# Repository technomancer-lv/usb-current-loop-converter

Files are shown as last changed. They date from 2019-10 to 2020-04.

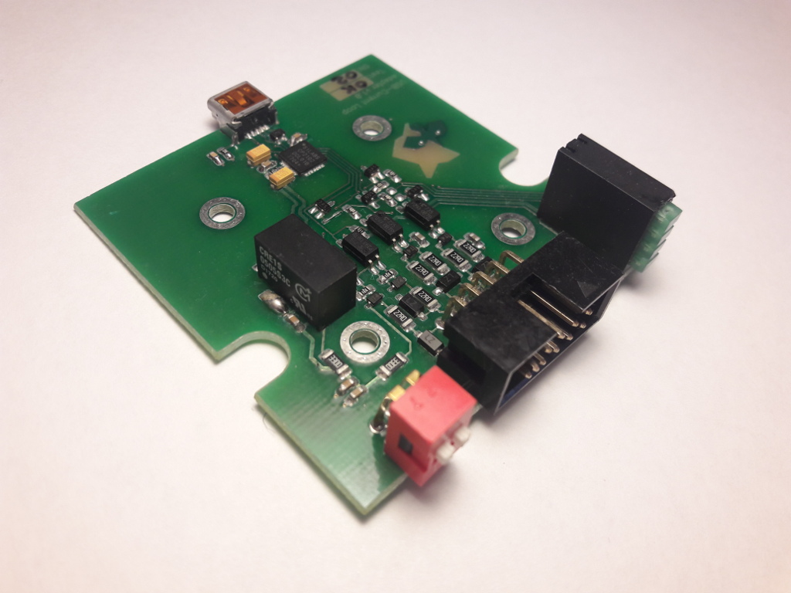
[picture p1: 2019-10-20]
pictures/01-cl-interface-top-1.jpg

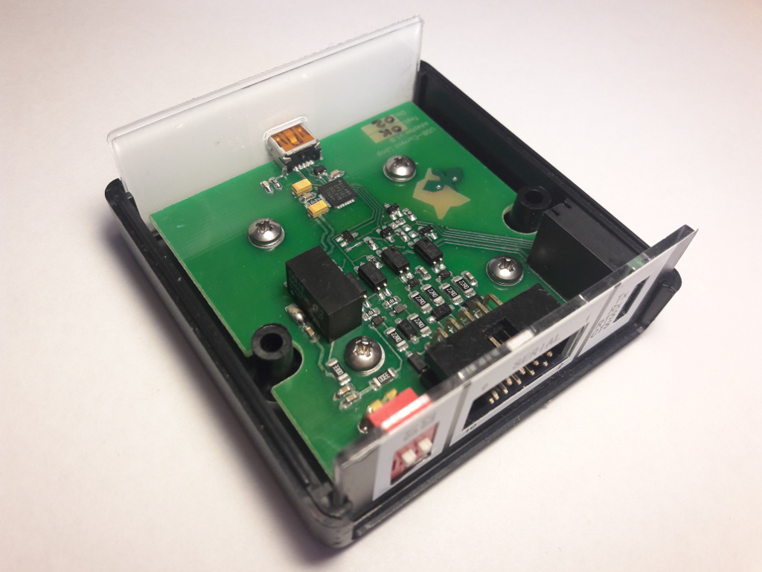
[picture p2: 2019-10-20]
pictures/04-cl-interface-in-case.jpg

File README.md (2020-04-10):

### What's this project for?
Current loop communication interface is used in various old computing equipment - computers, terminals, printers and other devices. This converter is made to let these devices interface with modern computers over USB port. It's based on CP2102 USB-serial bridge and can work up to 19200 baud.It's tested as working with soviet made PDP-11 compatible boards MS1201.01, 02, 03 (МС1201), computer DVK-3 (ДВК-3) or DVK-3M (ДВК-3М), serial interfaces UPO (УПО), I12 (И12), KTLK(КТЛК), KTLK-6 and also with terminals MS6102.02 (МС6102.02) and 15IE-00-013 (15ИЭ-00-013).

Converter is made as completed device in case that need only USB and current loop serial connections. Status of Tx, Rx, RTS and CTS lines are displayed on LEDs. Also, RTS and CTS signals can be forced to be active using DIP switches.

### What's the status of this project?
v1.0 is made and tweaked to work with various soviet made computing equipment. I have several of these converters in use and two are sold with good feedbacks from the buyers. Hardware version 1.2 is almost ready to be ordered. There are pulse stretcher for LEDs, so data activity will be displayed more visible. Data rate in prototype is 19200 bps.

Finished set will include:
  - Adapter itself
  - 0,5m long USB-mini cable
  - 1m long 10pin cable for connecting adapeter to 10pin interfaces
  - Small board for connecting 8pin interface to 10pin cable
  - Loopback connector
  
Additional parts possible:
  - Current loop interface cable for any other equipment, that's not supported by original adapter
  - Adapter board for connecting I12 serial controller to RS-232

### How to use it?
First, connect adapter to your computer with USB-mini cable. New serial port should appear in your system. If there's no new device found in your system, this might be a driver problem. You can download CP2102 drivers here:\
https://www.silabs.com/products/development-tools/software/usb-to-uart-bridge-vcp-drivers \
If you open terminal emulator (i.e. Realterm in Win or minicom in Linux) on this new port and type something, you should see Tx LED blinking as you type. You can test receive functionality of adapter with loopback plug. Connect it to serial port of your adapter and type something in terminal emulator. You should see both Tx and Rx LEDs blinking and symbols you type should echo back in terminal emulator screen.\
To connect emulator to your PDP-11 machine, use cable that comes with emulator. Cable can be directly connected to MS1201.02, .03 and .04 board terminal port and also DVK-3M terminal port. If boards with 8-pin connector needs to be connected (for example, UPO, I12, MS1201.01 or older revisions of .02), it can be done with adapter board. Simply connect cable to adapter board and plug it into terminal port of your retro computer. RTS and/or CTS might have to be forced on, otherwse computer might refuse to send data.\
Be sure that baudrate of terminal emulator is set correctly, switch on your PDP-11 compatible machine and you should see ODT prompt. That's it!

### What has to be done?
v1.2 should be properly tested on various equipment\
v1.2 should be properly packed up and sold in soviet retro computer related forums

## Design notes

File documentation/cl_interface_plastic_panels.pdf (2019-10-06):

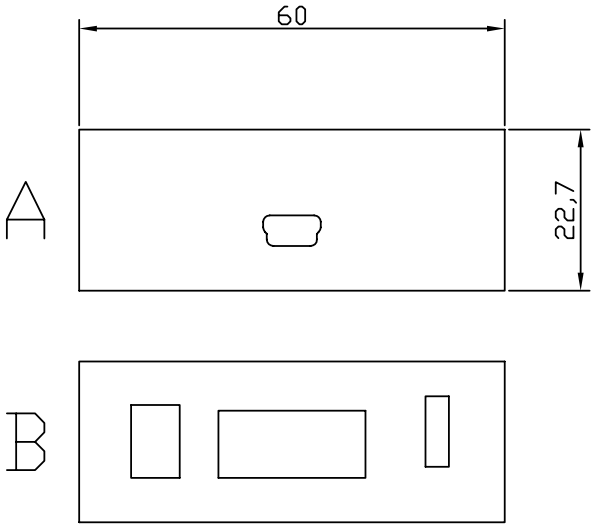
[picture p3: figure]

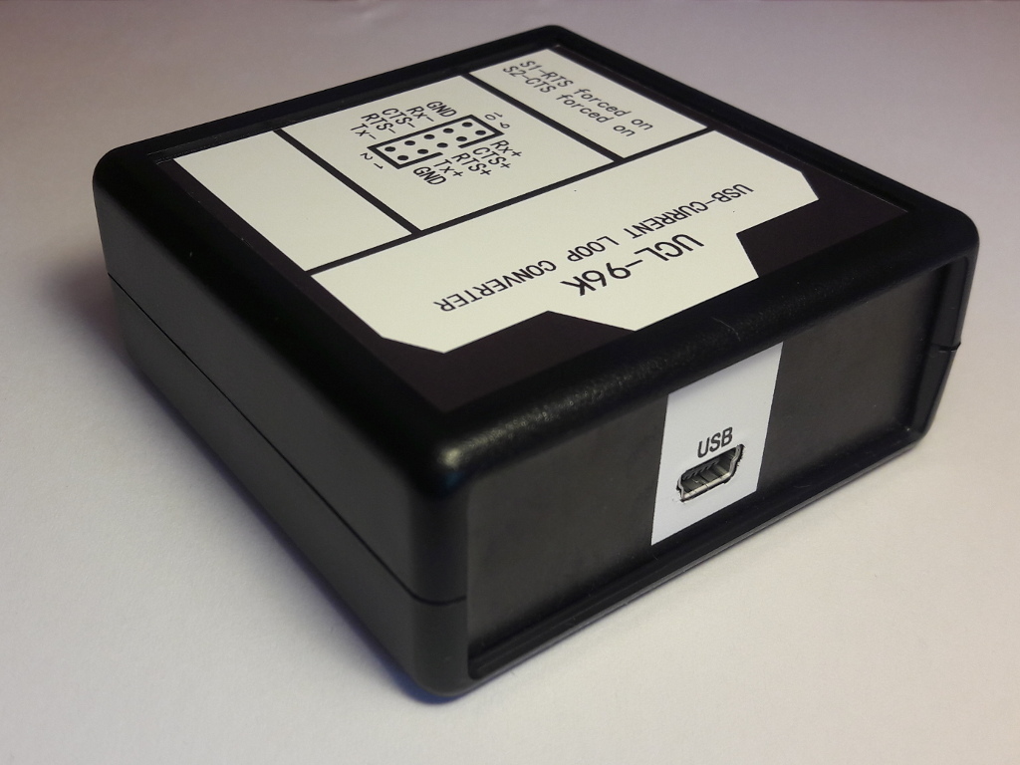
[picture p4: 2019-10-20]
pictures/06-cl-interface.jpg

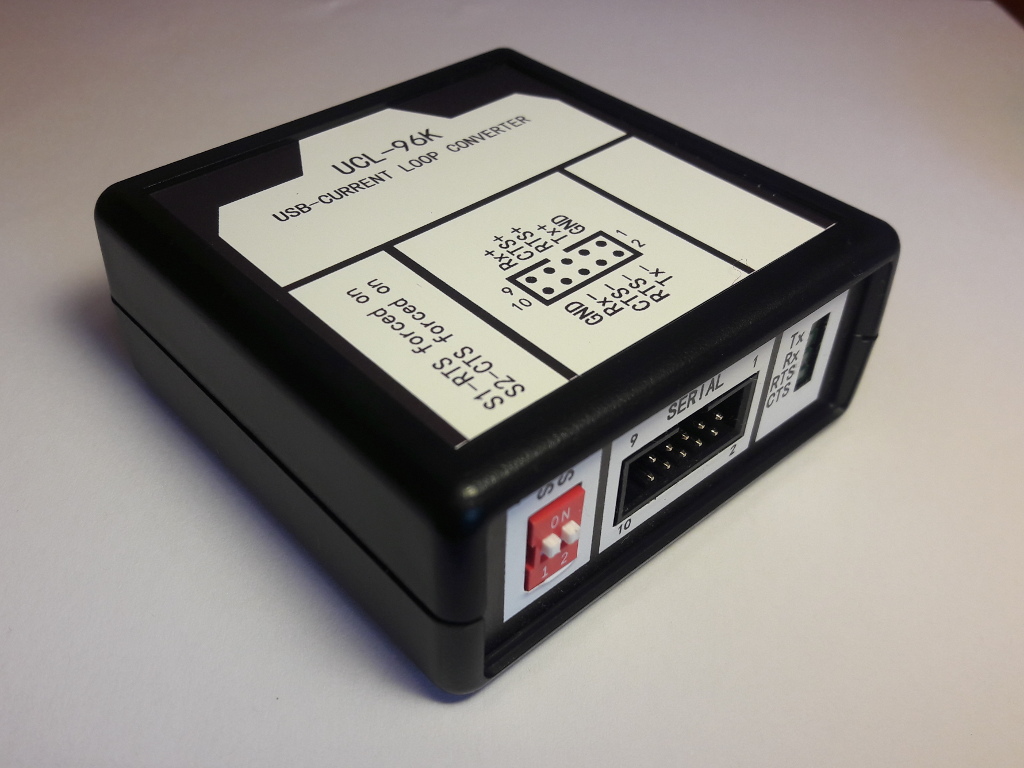
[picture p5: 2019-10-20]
pictures/05-cl-interface.jpg

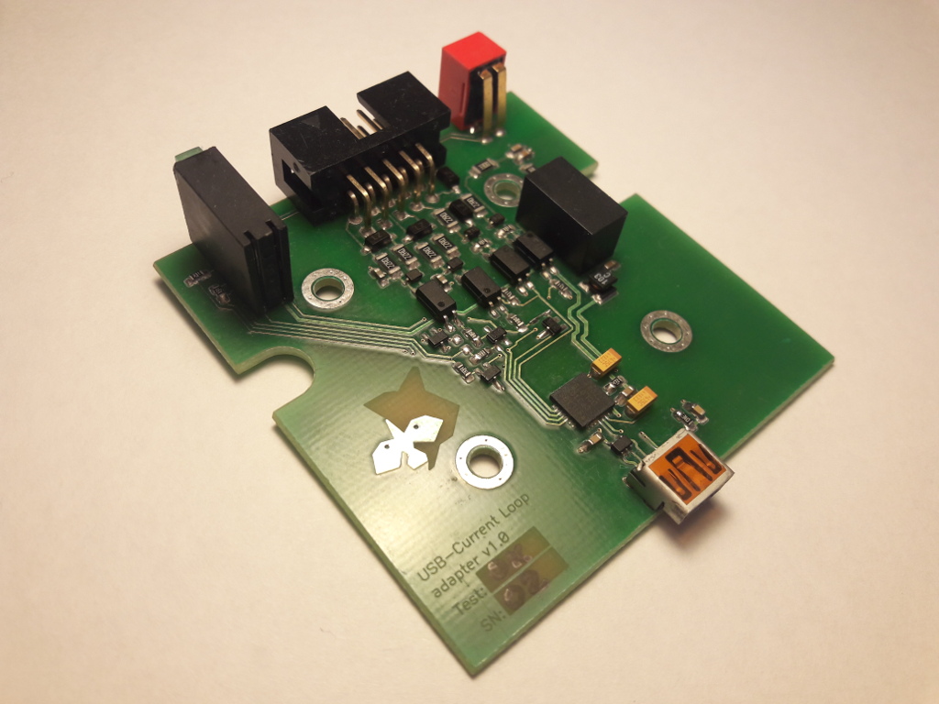
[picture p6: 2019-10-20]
pictures/02-cl-interface-top-2.jpg

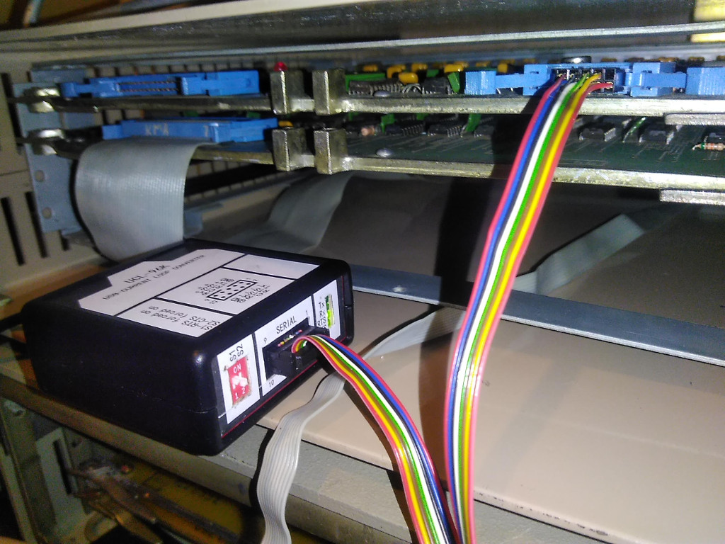
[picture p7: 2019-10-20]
pictures/07-cl-interface-connected.jpg

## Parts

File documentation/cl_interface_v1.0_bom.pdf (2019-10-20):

Sheet1

Page 1

RefDes | Part number | Count | Distributor | Order Nr. | Remarks | Price, each, Eur | Price per board
C1 | | 1 Ormix | | | 4700pF, 0603 | 0,03 | 0,03
C2,C4,C6,C9 | | 4 Ormix | | | 0,1uF 0603 | 0,03 | 0,12
C3,C5 | TAJA475K016R | 2 Ormix | | | 4,7uF, type A tantalum | 0,25 | 0,5
C7, C8 | | 2 Ormix | | | 1,0uF, 0603 | 0,05 | 0,1
C10,C11 | | 2 Ormix | | | 1500pF | 0,03 | 0,06
D1 | SP0504BAJTG | 1 Farnell | | | 1,05 | 1,05
D2, D3, D4, D5, D6 | 1N4148WS | 5 Ormix | | | 0,2 | 1
D7, D8, D9, D10 | ATV02W240B-HF | 4 Digikey | 641-1660-1-ND | EOL? | 0,37 | 1,48
JP1 | 51387-0578 | 1 Farnell | 2751685 | 1,01 | 1,01
JP2 | BH1R-10 | 1 Ormix | | 0,23 | 0,23
L1 | 82103C | 1 Digikey | 811-2473-1-ND | 0,32 | 0,32
LED1 | WP914CK/4GDT | 1 Digikey | 754-1286-ND | 1,5 | 1,5
Q1, Q2, Q3 | BC807-25WT1G | 3 Farnell | 2533298 | 0,13 | 0,39
Q4 | | 1 Farnell | 8737045 | 0,17 | 0,17
R1 | 0603-1M-F 0603-4.7K-F | 1 Ormix | | 0,005 | 0,005
R2 | | 1 Ormix | | 0,004 | 0,004
R3, R4 | | 2 Ormix | Optional | | 0
R5, R7, R8, R9 | 0603-330om-F | 4 Ormix | | 0,004 | 0,016
R6 | | 1 Ormix | Unpopulated | | 0
R10, R11 | 0603-470om-F 0603-68om-F 0603-330om-F 1206-330om-F 1206-22om-F | 2 Ormix | | 0,004 | 0,008
R12, R13 | | 2 Ormix | | 0,004 | 0,008
R14, R15 | | 2 Ormix | | 0,004 | 0,008
R16, R17 | | 2 Ormix | | 0,02 | 0,04
R18, R19, R20, R21, R22, R23 | | 6 Ormix | | 0,02 | 0,12
SW1 | MCDA02 | 1 Farnell | 1255229 | EOL | 0
U1 | CP2102-GM | 1 Farnell | 9282130 | | 3,16 | 3,16
U2 | CRE1S0505S3C | 1 Farnell | 2564448 | Optional | 2,46 | 2,46
U3, U4, U5, U6 | TLP293 | 4 Farnell | 2524317 | | 0,386 | 1,544
PCB | According to gerber files | 1 JLCPCB | | | 3 | 3
Case | 1593KBK | 1 Farnell | 930180 | Plastic panels replaced with custom ones | 2,98 | 2,98
Screws | | 4 Delve2 | | For fixing PCB in case | 0,05 | 0,2
Plastic panels | According to drawings | 1 Kviller | | | 1,5 | 1,5
Stickers | According to drawings | 1 CopyPro | | | | 0
Ormix – local radio parts shop | Price, overall (No VAT): | 23,013
Delve2 – local screw shop | Price (+VAT): | 27,84573
Kviller – local laser cutting contractor
CopyPro – local printing service

Additional parts:
Interconnect cable
IDC connector | FC-10 | 1 Ormix | 0
Cable | F0801-10P | 1 Ormix | 0
| | | 0
| | | 0
Serial cable:
Mini USB cable

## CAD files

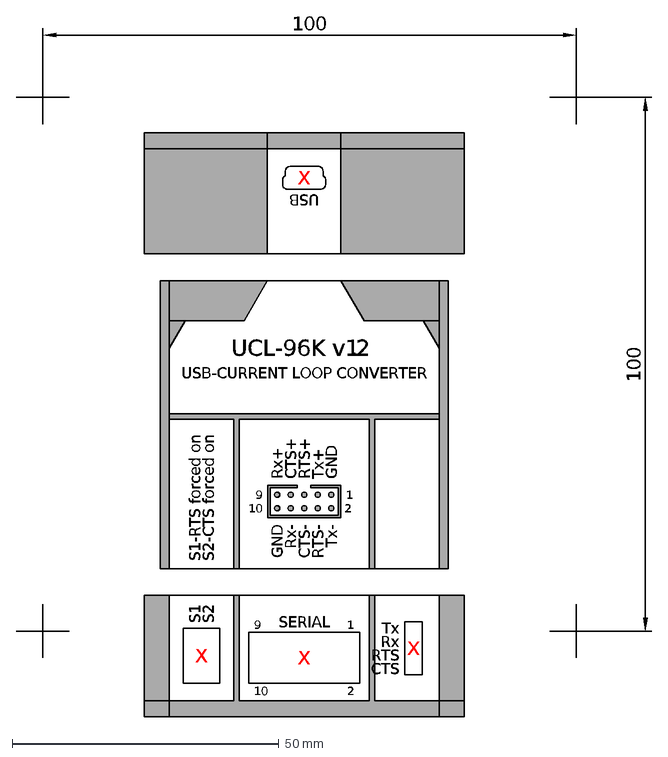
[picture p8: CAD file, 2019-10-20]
cad/stickers.dxf
Tx
Rx
RTS
CTS
S1
S2
SERIAL
USB
1
2
9
10
S1-RTS forced on
S2-CTS forced on
Tx-
CTS-
RTS-
Rx-
GND
Tx+
CTS+
RTS+
Rx+
X
UCL-96K v1
USB-CURRENT LOOP CONVERTER
100
.

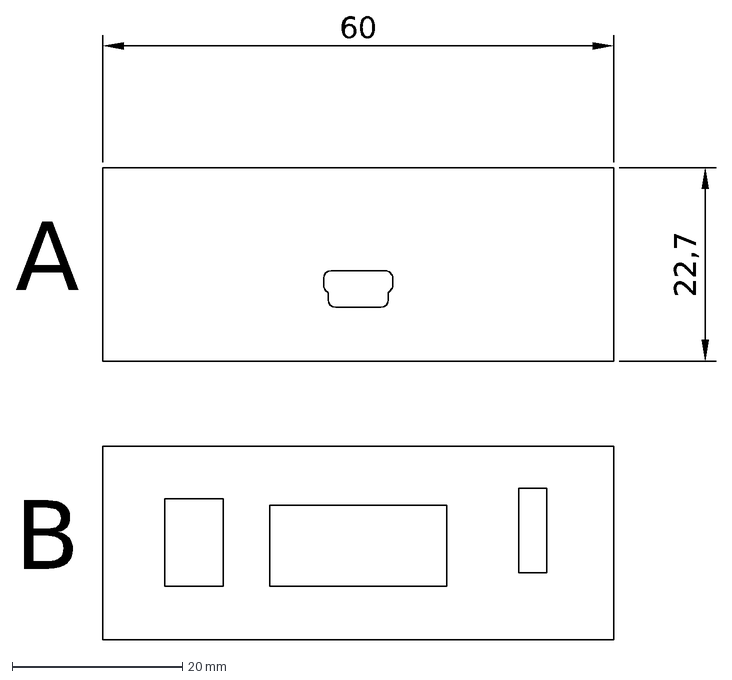
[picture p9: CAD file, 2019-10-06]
cad/plastic_panels.dxf
60
22,7
A
B

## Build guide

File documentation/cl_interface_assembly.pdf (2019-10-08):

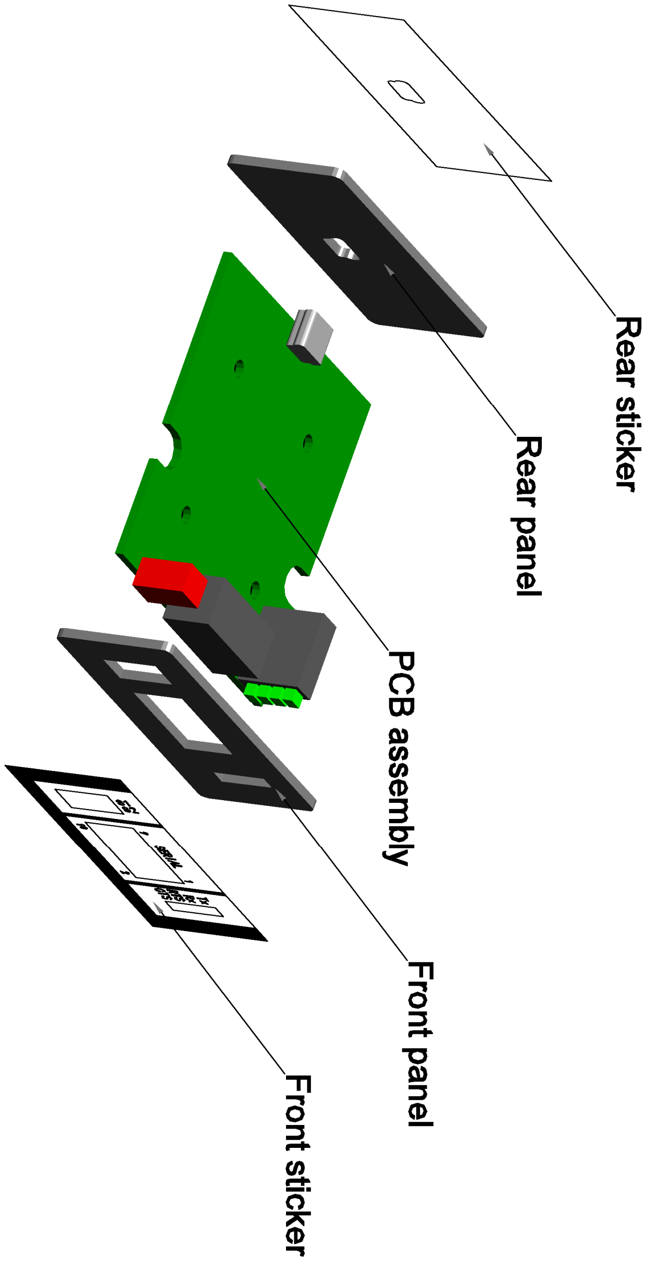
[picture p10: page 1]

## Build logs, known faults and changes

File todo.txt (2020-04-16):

Workflow 2020:
	Make cables (17.02) (6pcs made, waiting for connectors)
	Solder adapter boards (5 done, waiting for connectors)
	Test all sets
	Put all in boxes (converter, small board, loopback plug, interface cable, USB cable, sticker)
	Sell 8pcs
	
	Add finished set pictures here

v1.2:	sch:
	BOM should be re-checked when finished - count, values, links
      
  another small PCB for 8-pin connector
	check if everything fits and works on 1201, UPO and I12 boards (1201 and UPO tested)
	also make 8pin-DE9M adapter for I12 (witn insulators?) (unrelated to CL, only RS232)
    
  make full documentation
  make BOM
  proper testing (MS1201.01 .02 .03, terminals)
  cable pinouts for various devices and loopback cable
  better assembly drawing
    
  make set for sale
    make pictures with packed up set
    make pictures with new version and adapter boards
    
Maybe cheap lite version with no case, no RST/CTS, all DIP?
    With cheap ebay UART module
    Component values on board
    Sold as simple board to be assembled by buyer

Design a convertor for RS232-IRPS
Maybe one with BK KMK module compatible pinout?
Maybe one with MC6102 optical UART compatibility?

Issues:
  A bit incorrect resistor numbering at the CL connector. Fix in next release if there will be one.

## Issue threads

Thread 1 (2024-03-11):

FEATURE REQUEST: Export .pcb files as PCAD ASCII PCB files

nightgryphon, 2024-03-11:
Пожалуйста, могли бы вы экспортировать файлы печатных плат в ASCII PCB формате? BIN PCB формат не берет KiCAD к сожалению. Хотел собрать панель для самостоятельной распилки с переходниками вместе...

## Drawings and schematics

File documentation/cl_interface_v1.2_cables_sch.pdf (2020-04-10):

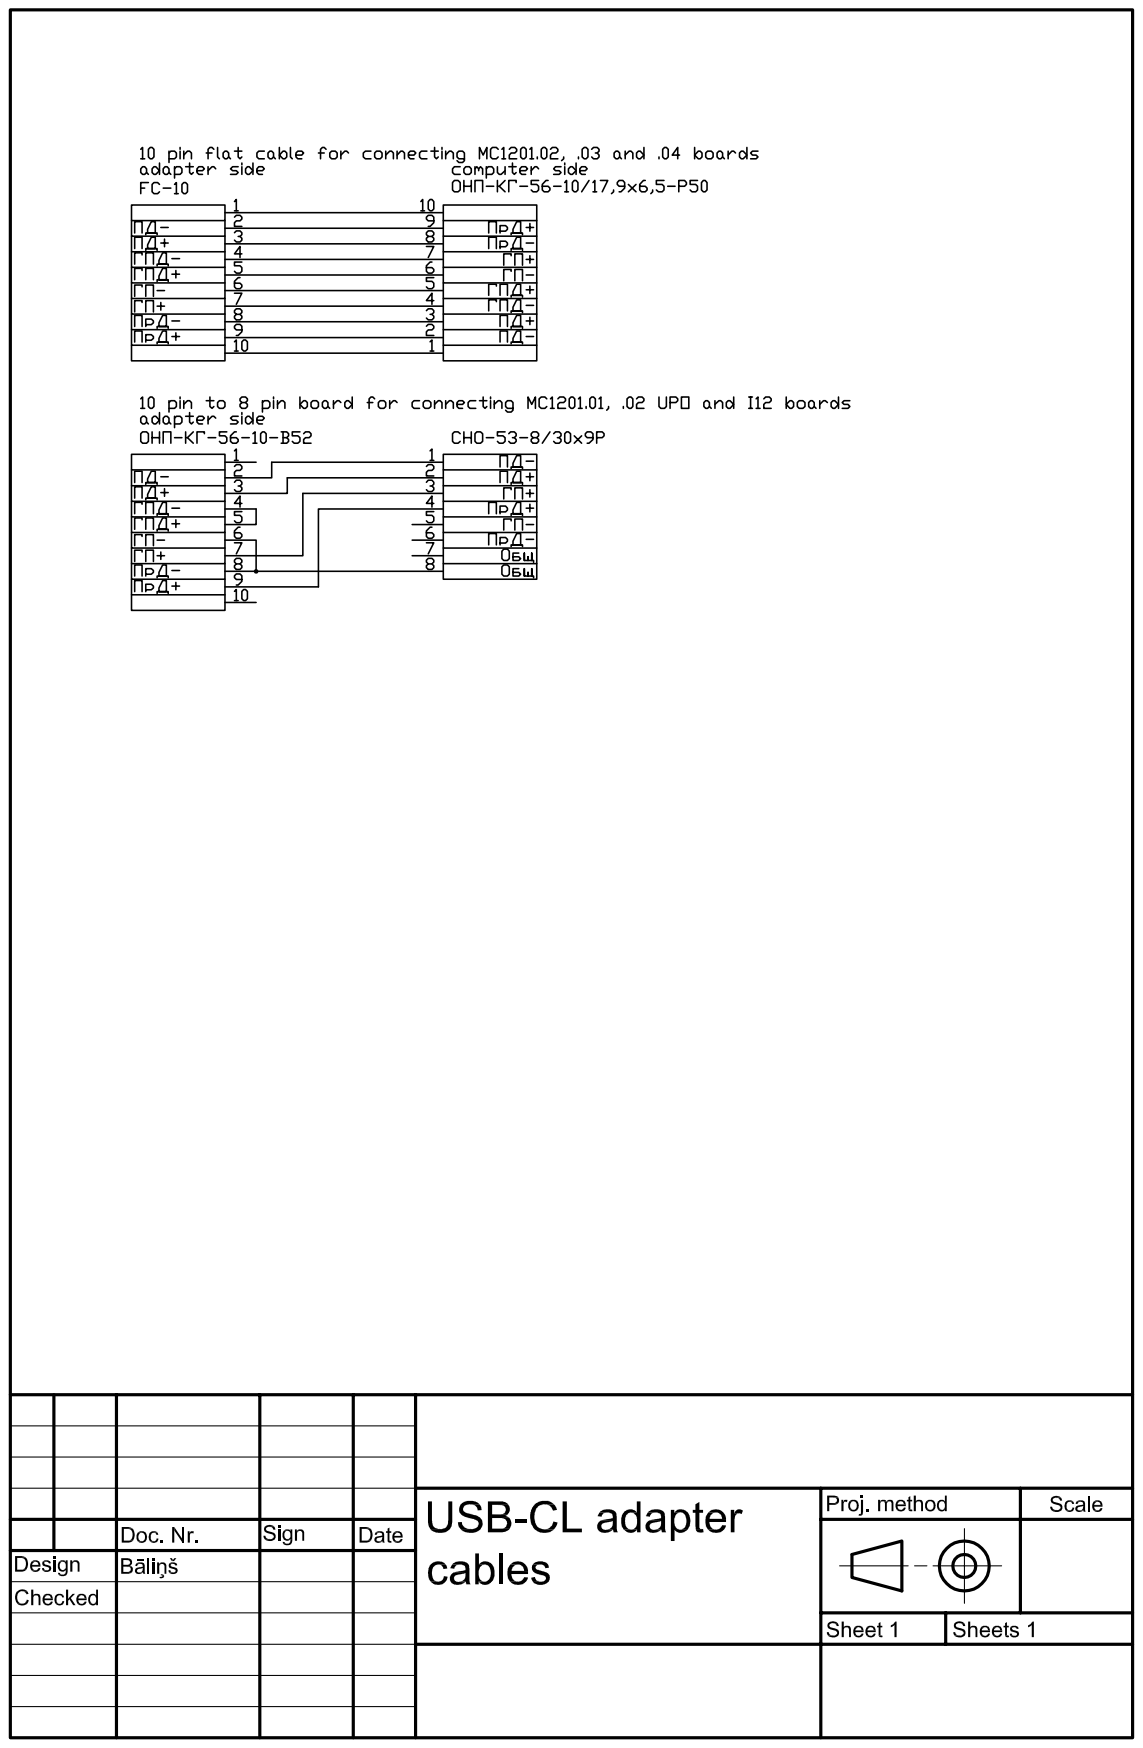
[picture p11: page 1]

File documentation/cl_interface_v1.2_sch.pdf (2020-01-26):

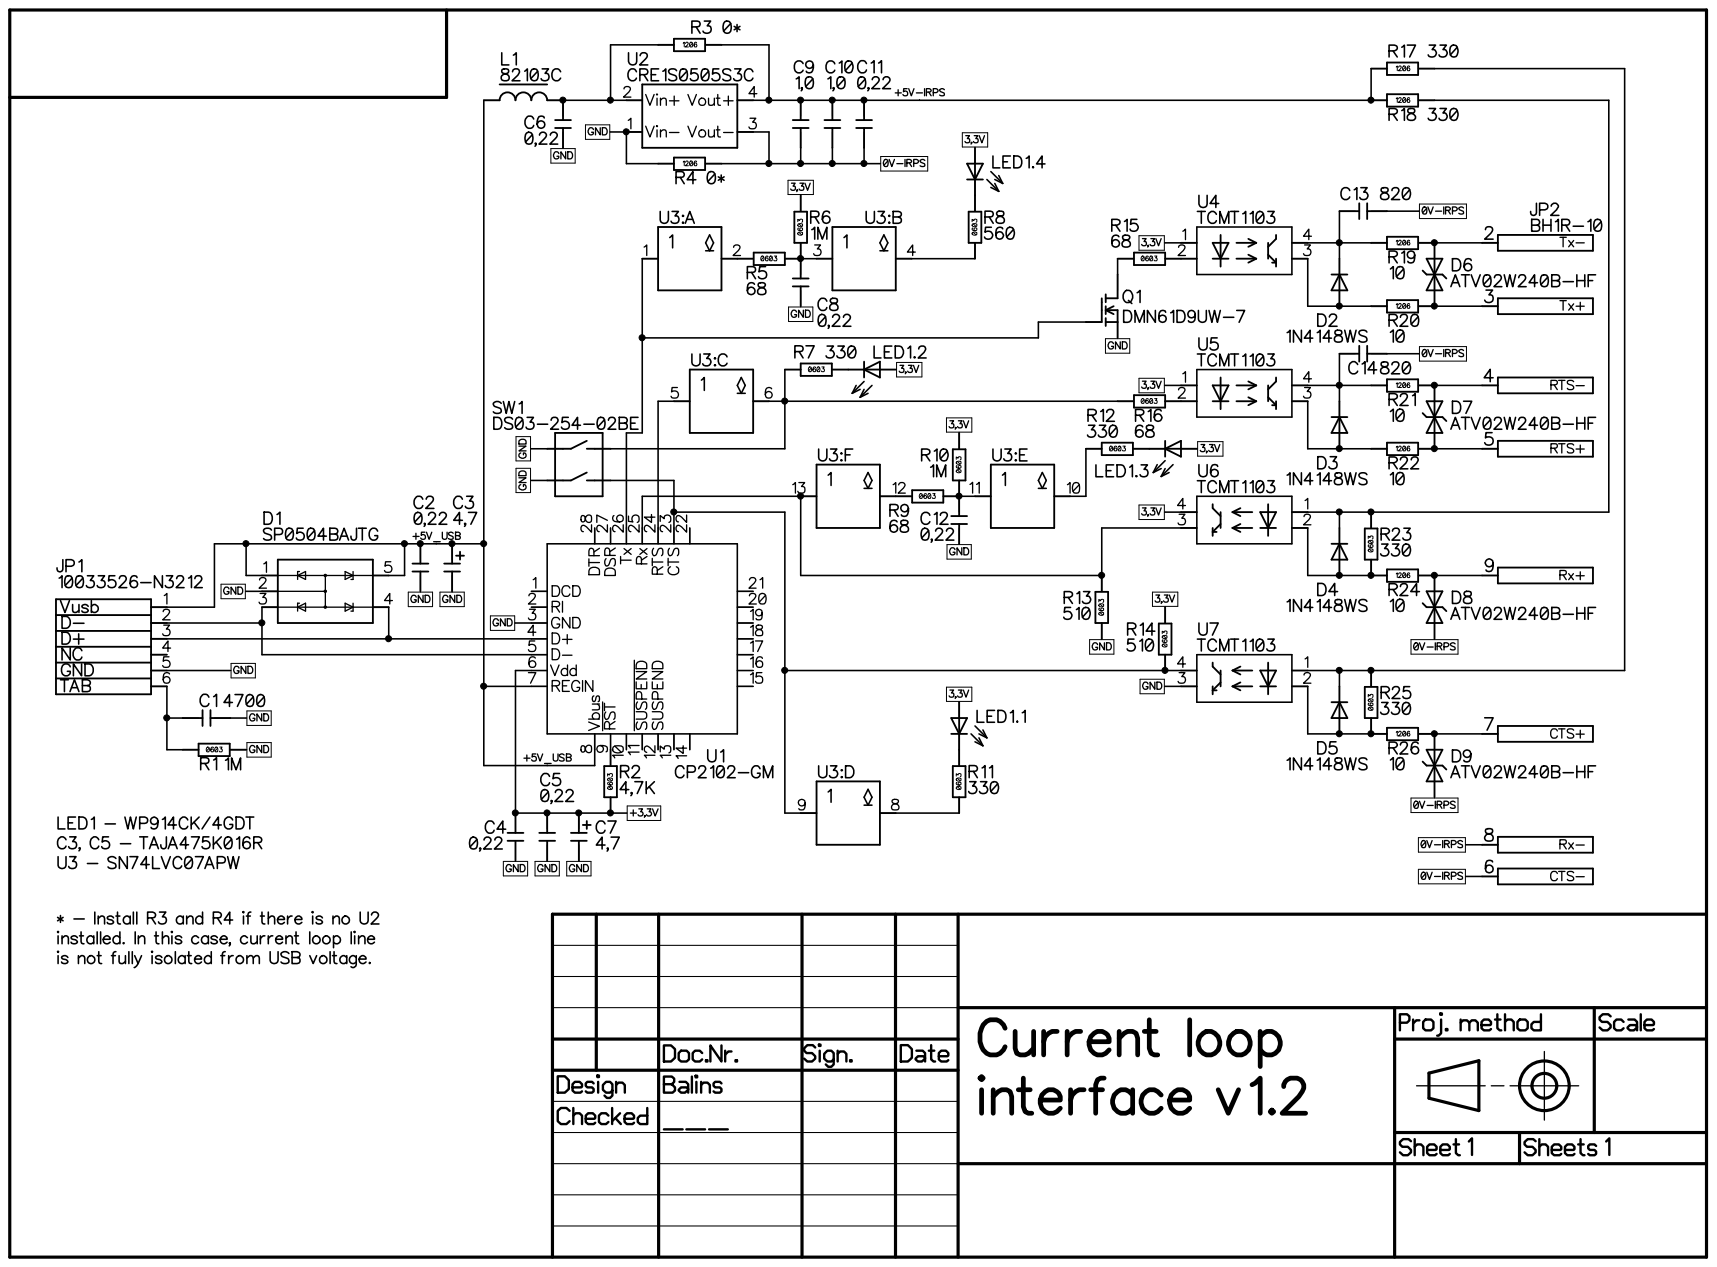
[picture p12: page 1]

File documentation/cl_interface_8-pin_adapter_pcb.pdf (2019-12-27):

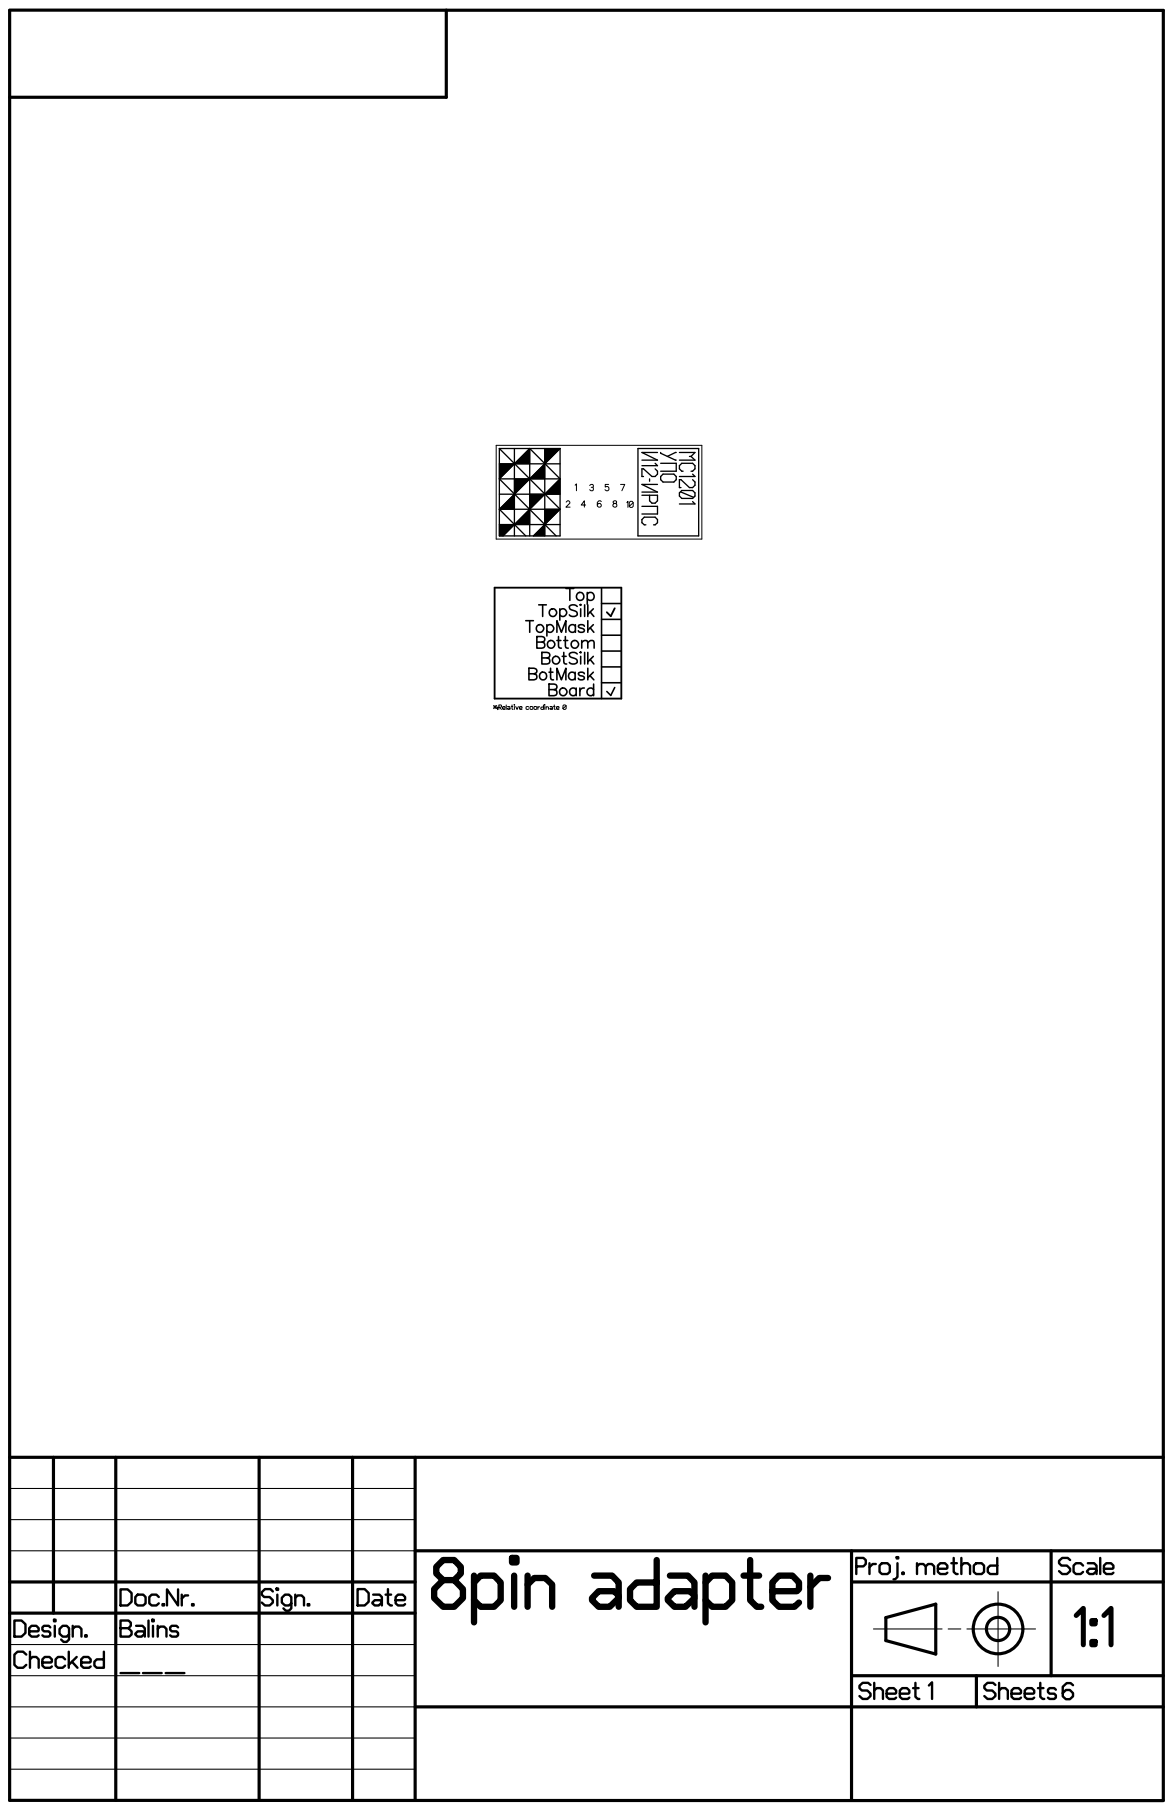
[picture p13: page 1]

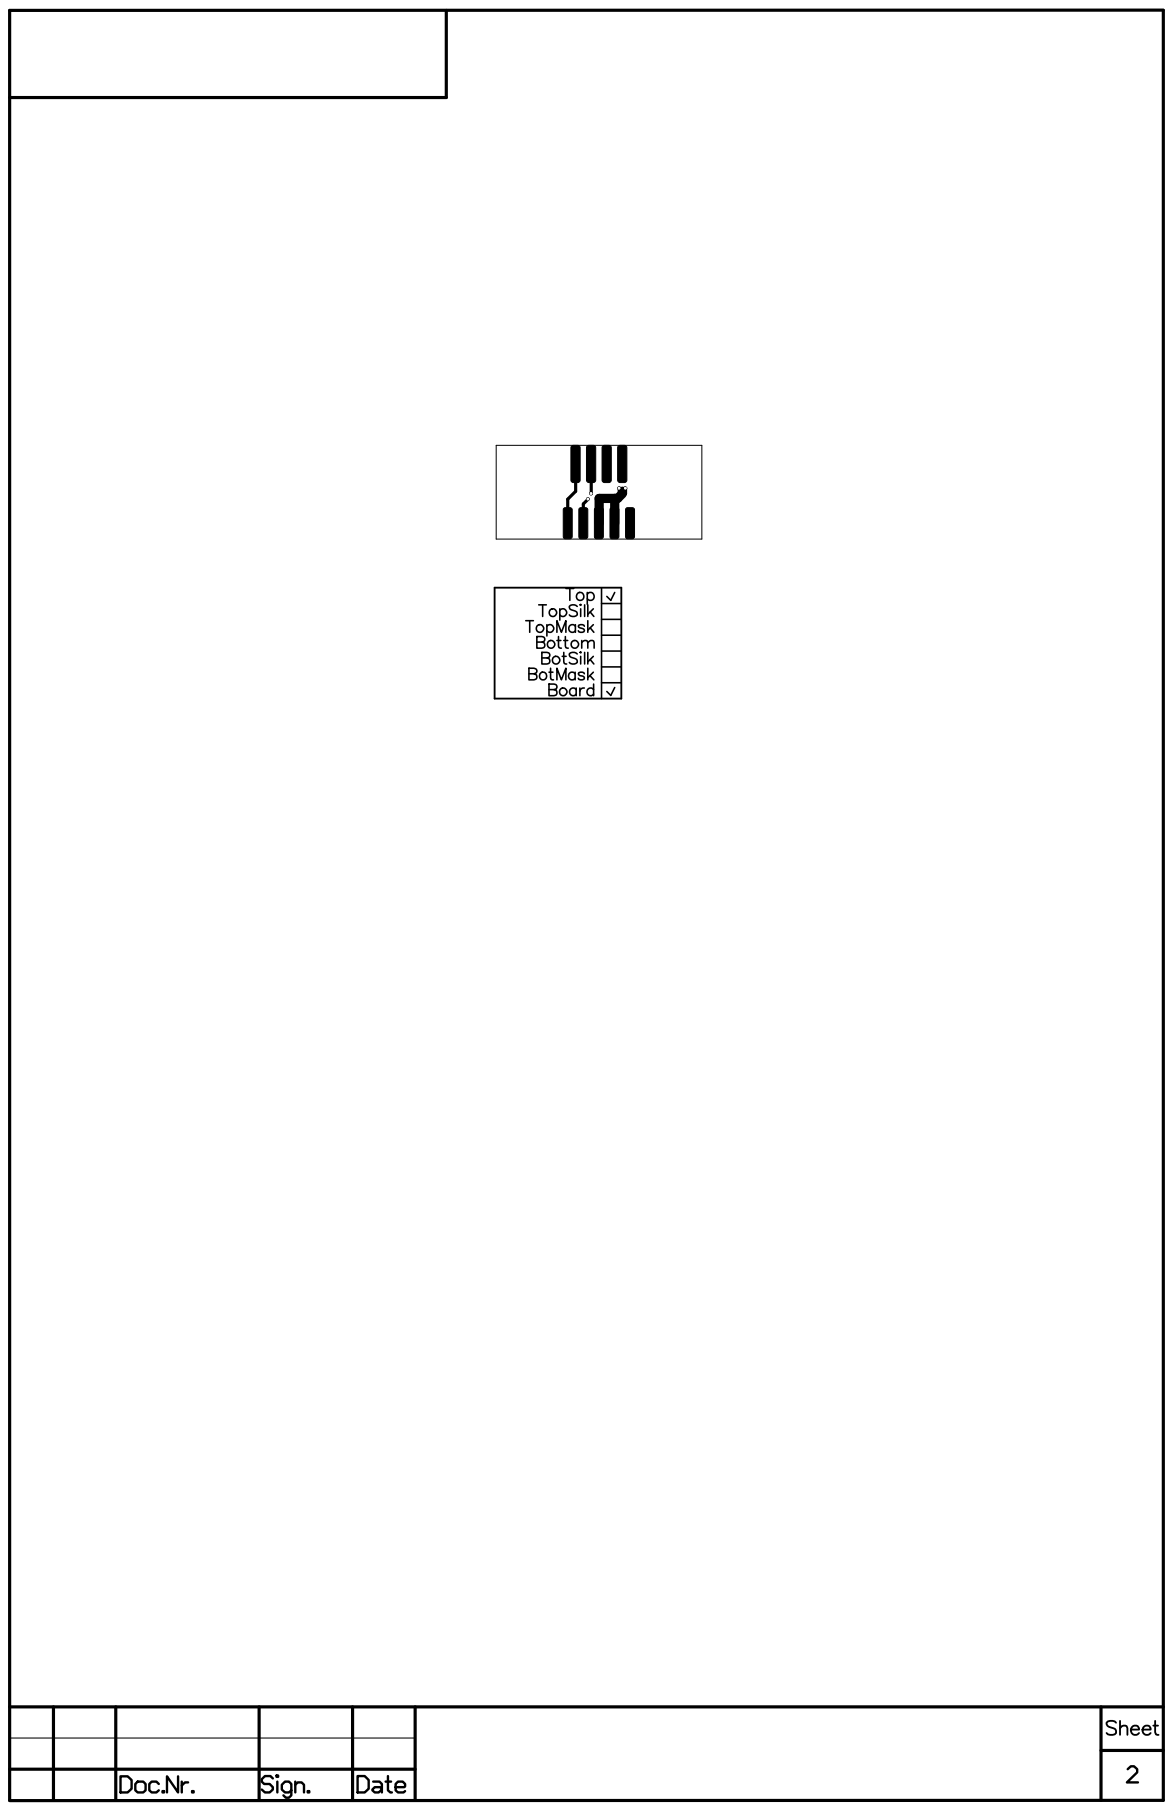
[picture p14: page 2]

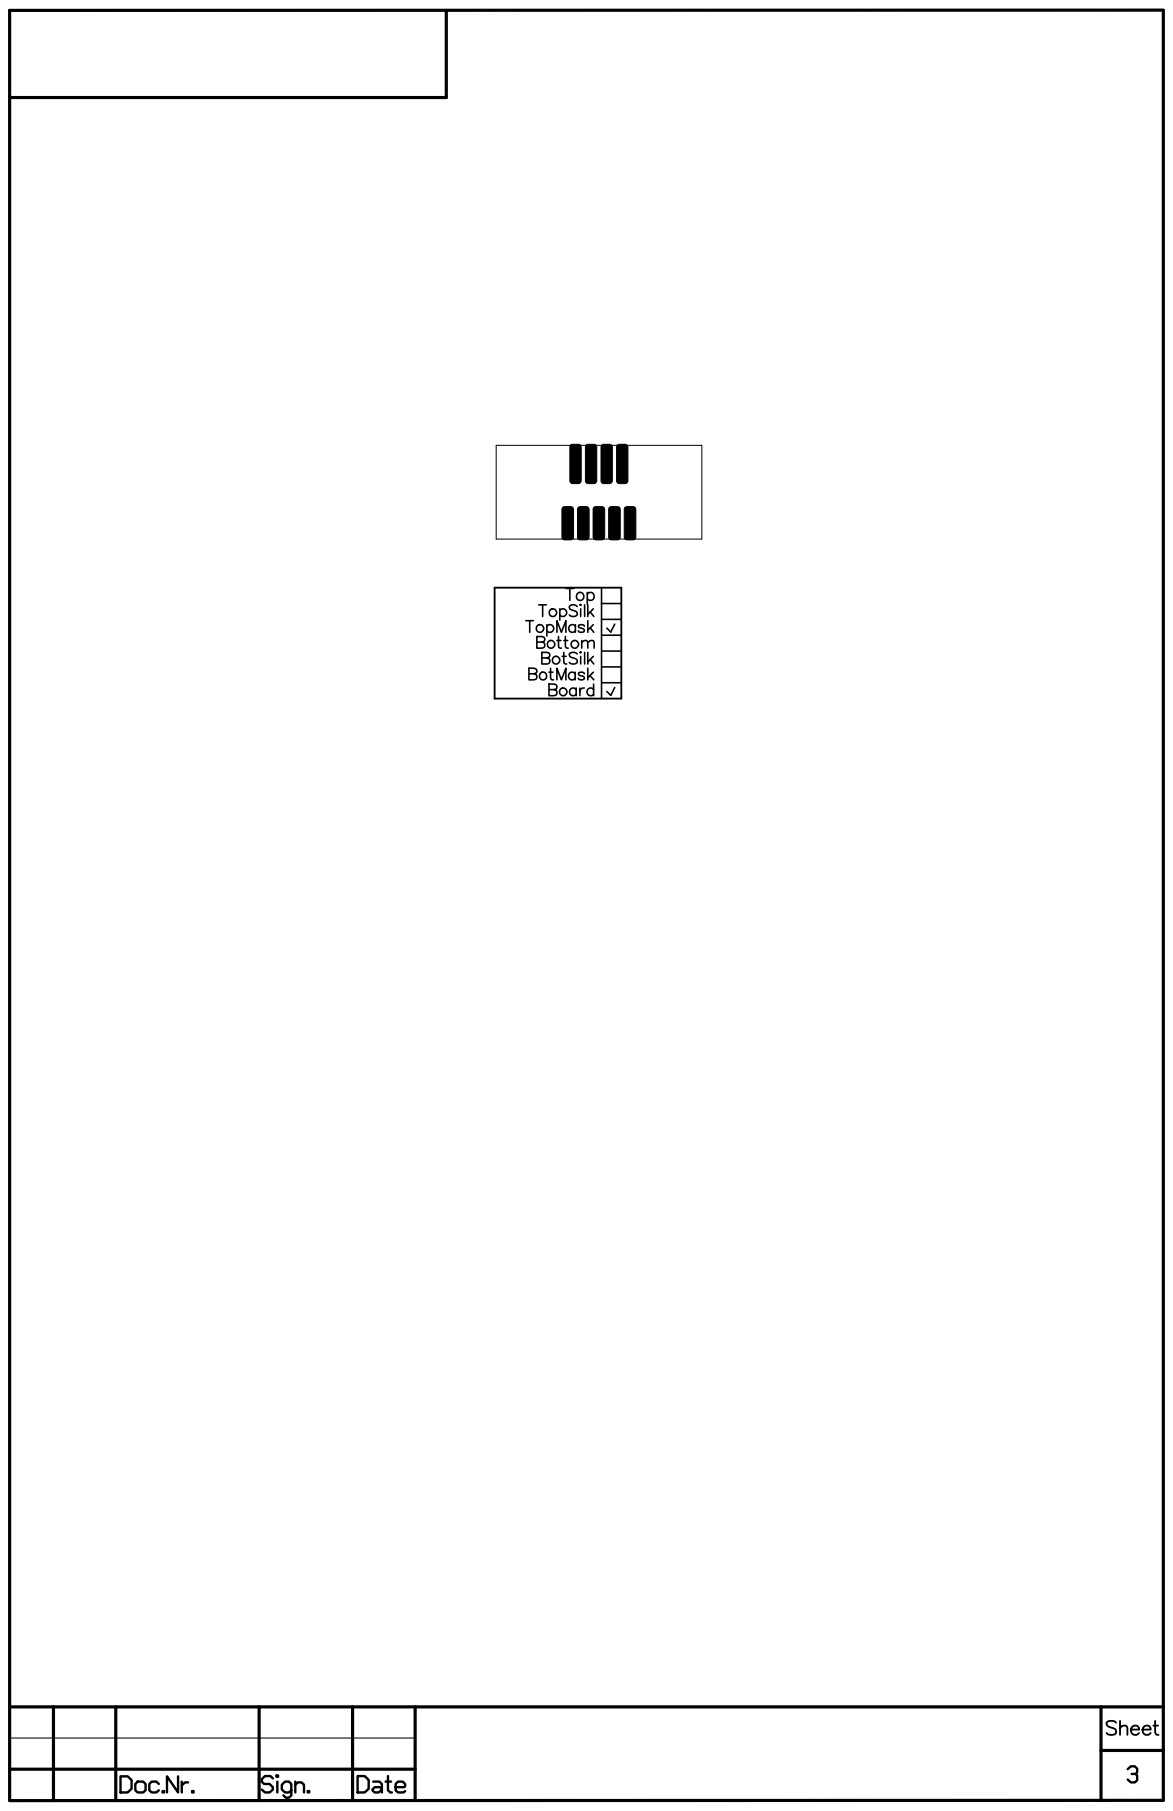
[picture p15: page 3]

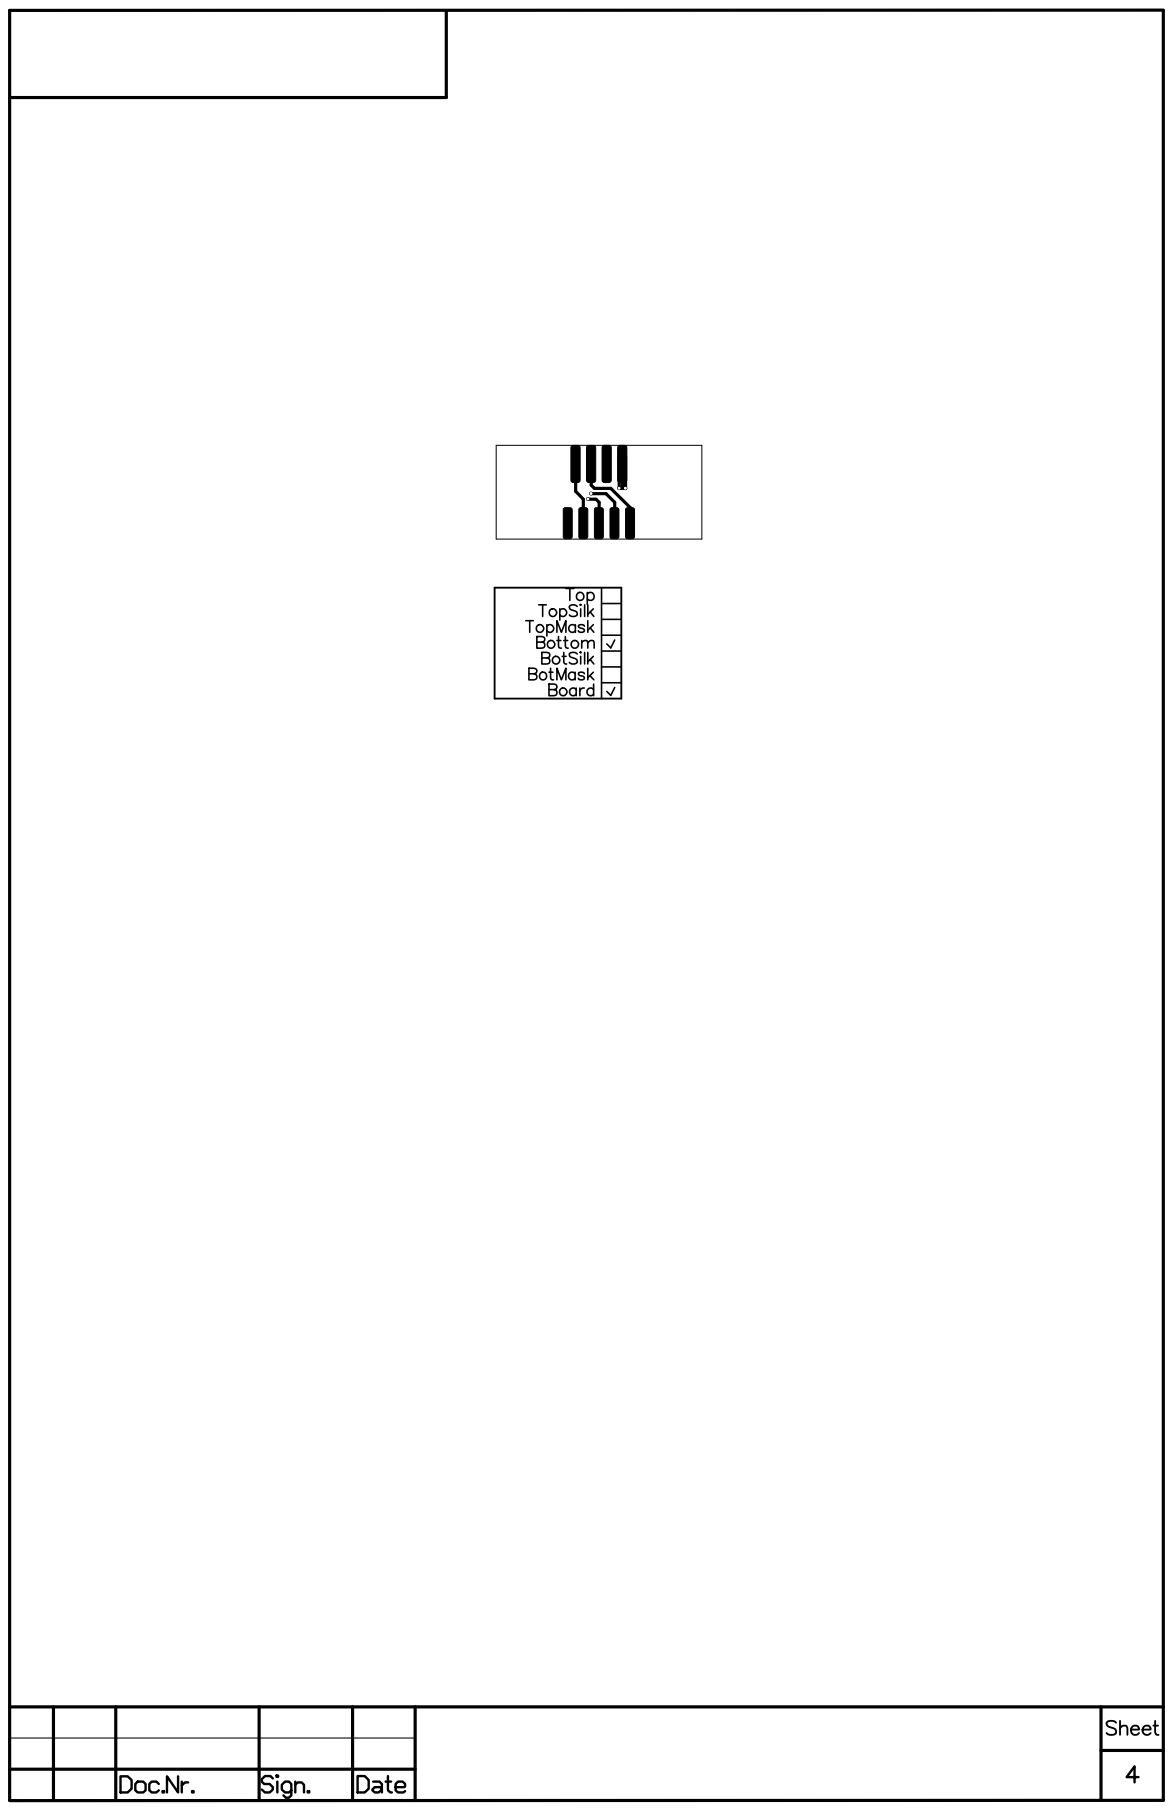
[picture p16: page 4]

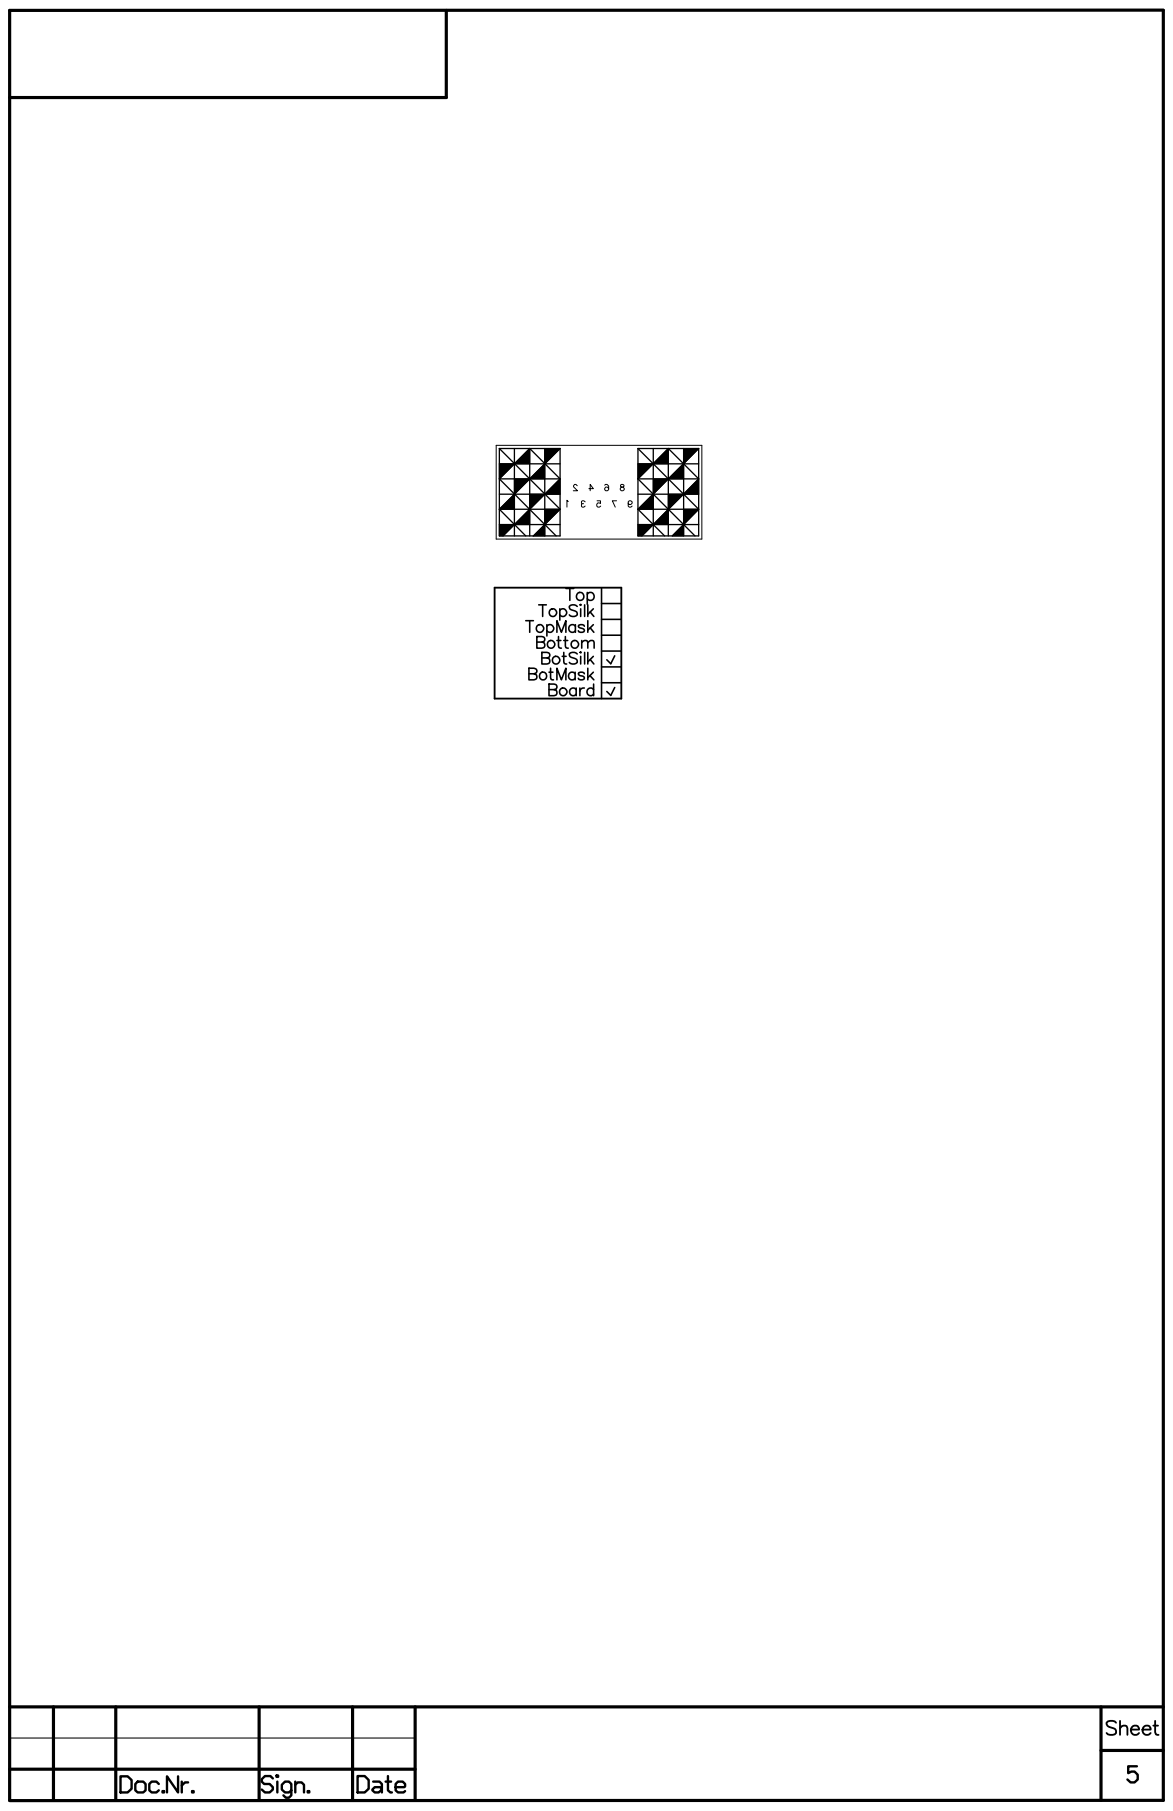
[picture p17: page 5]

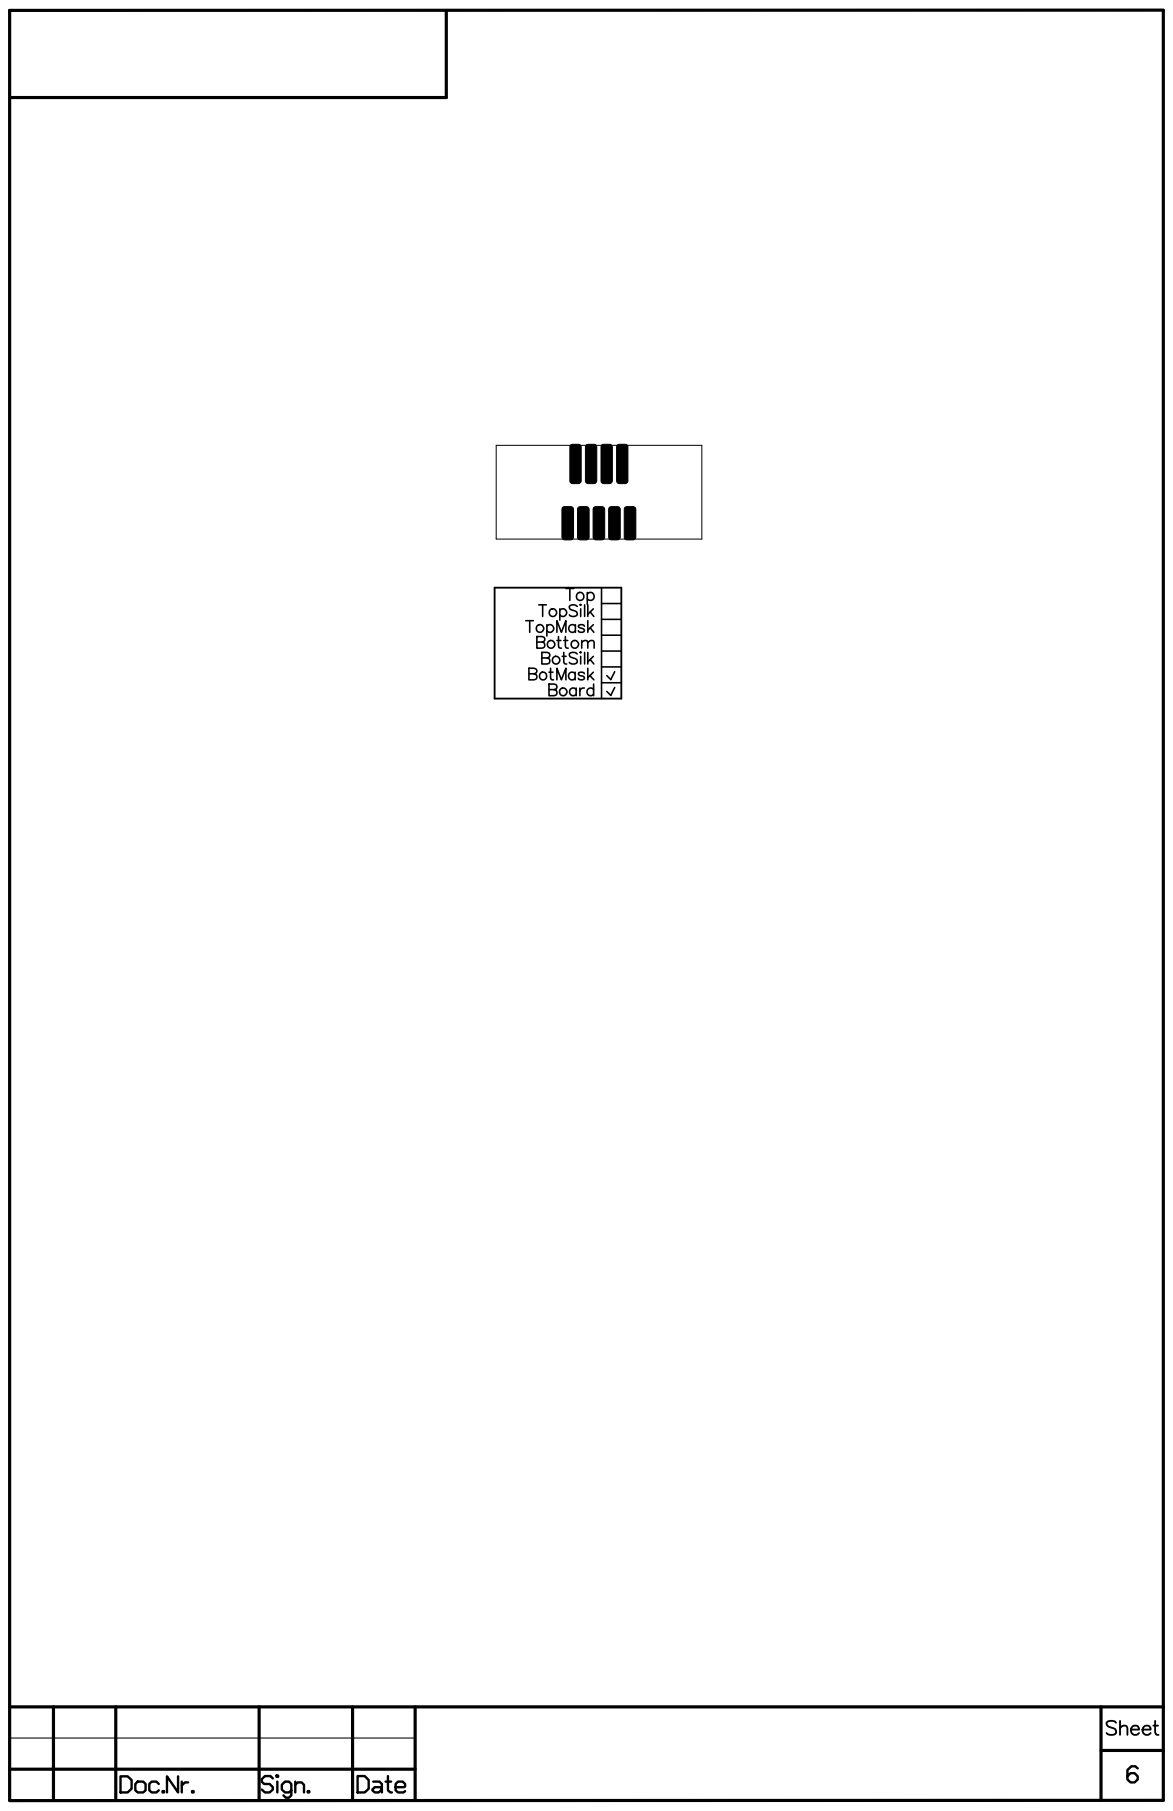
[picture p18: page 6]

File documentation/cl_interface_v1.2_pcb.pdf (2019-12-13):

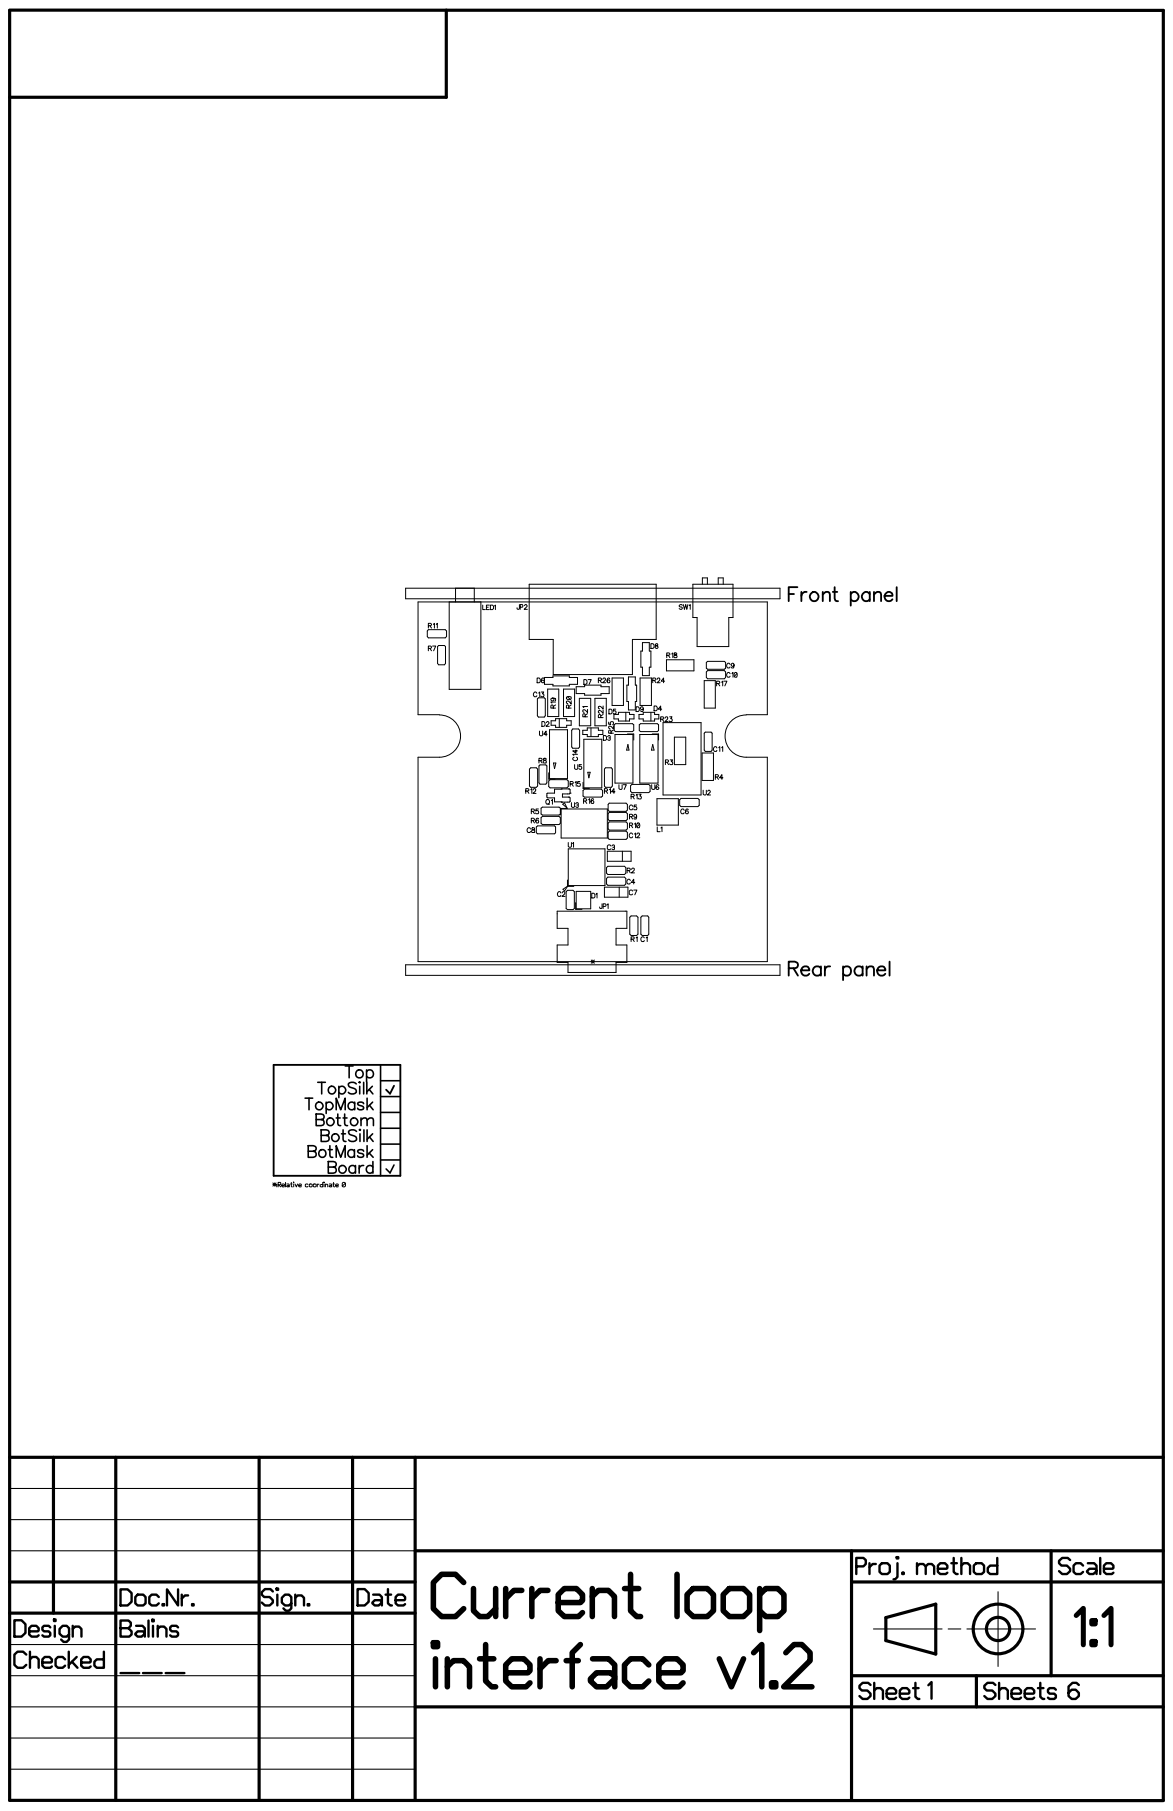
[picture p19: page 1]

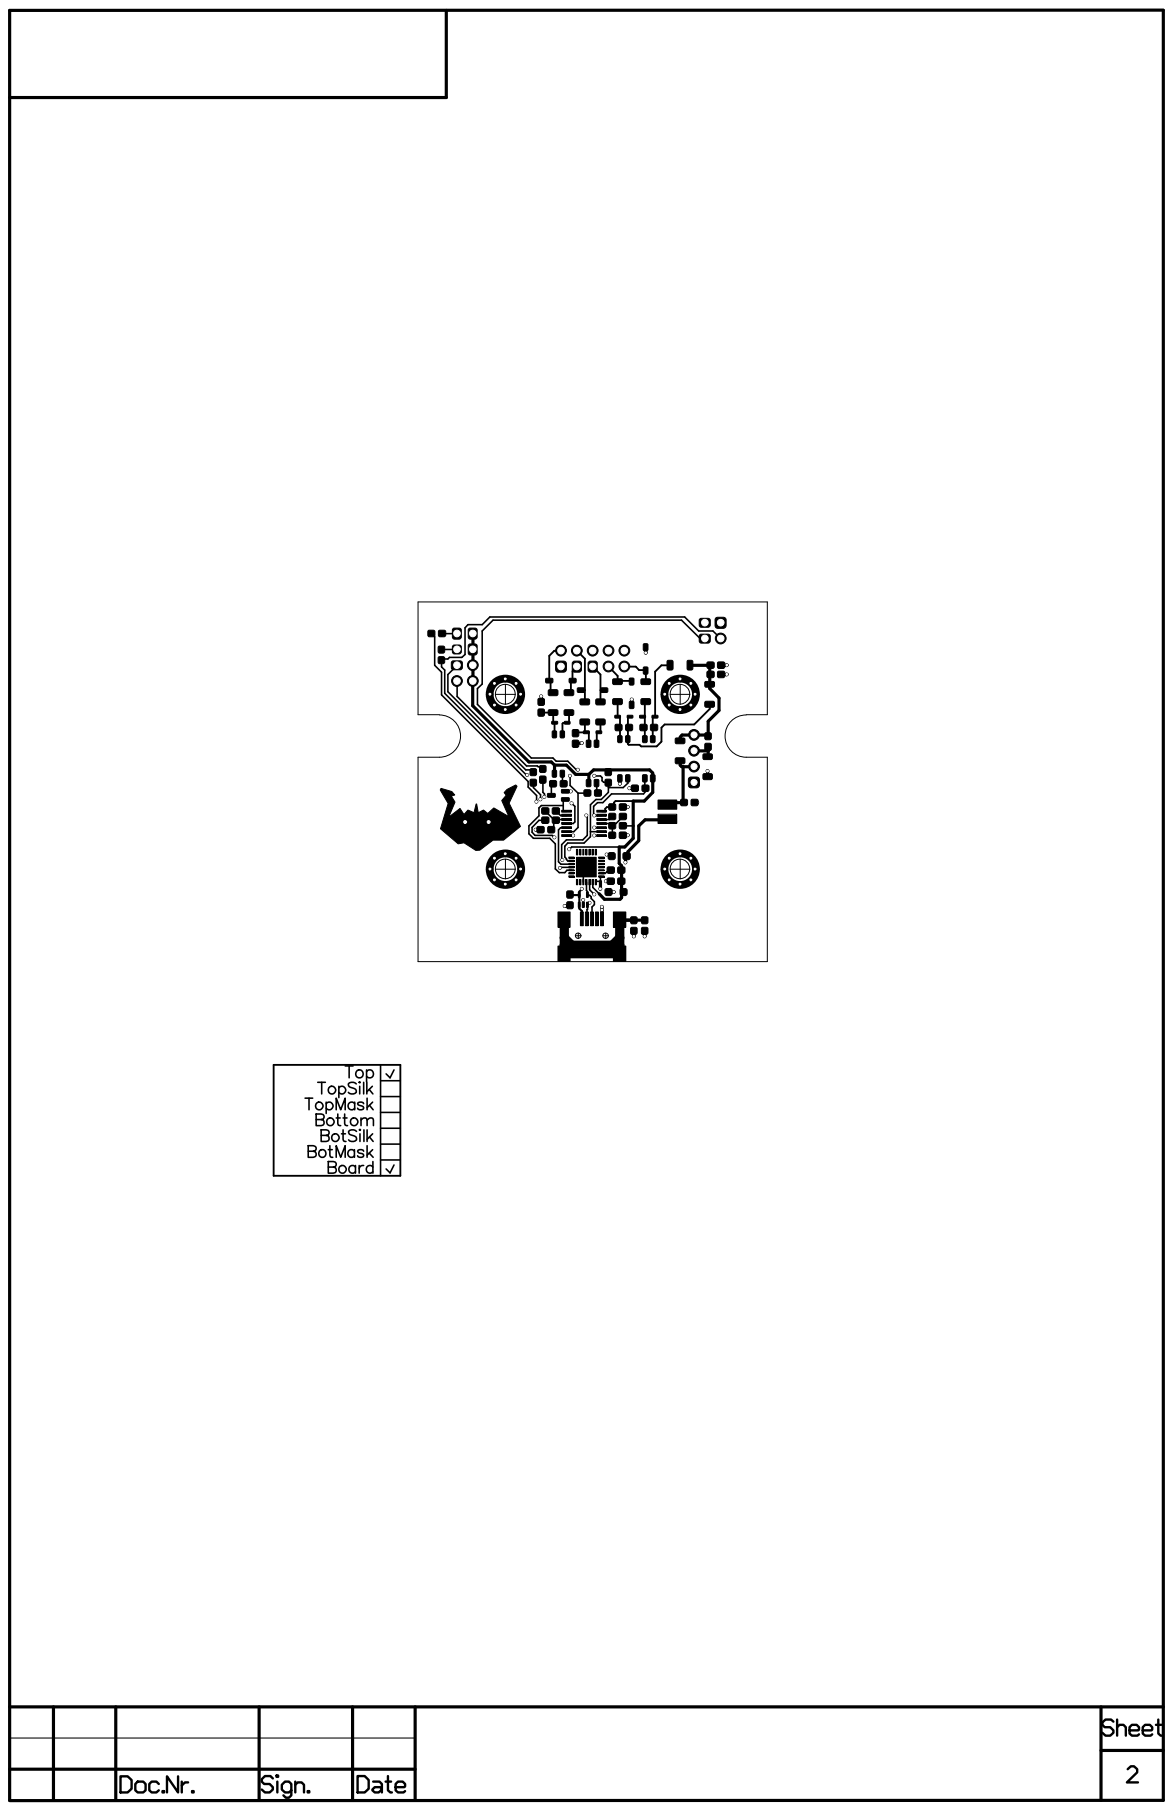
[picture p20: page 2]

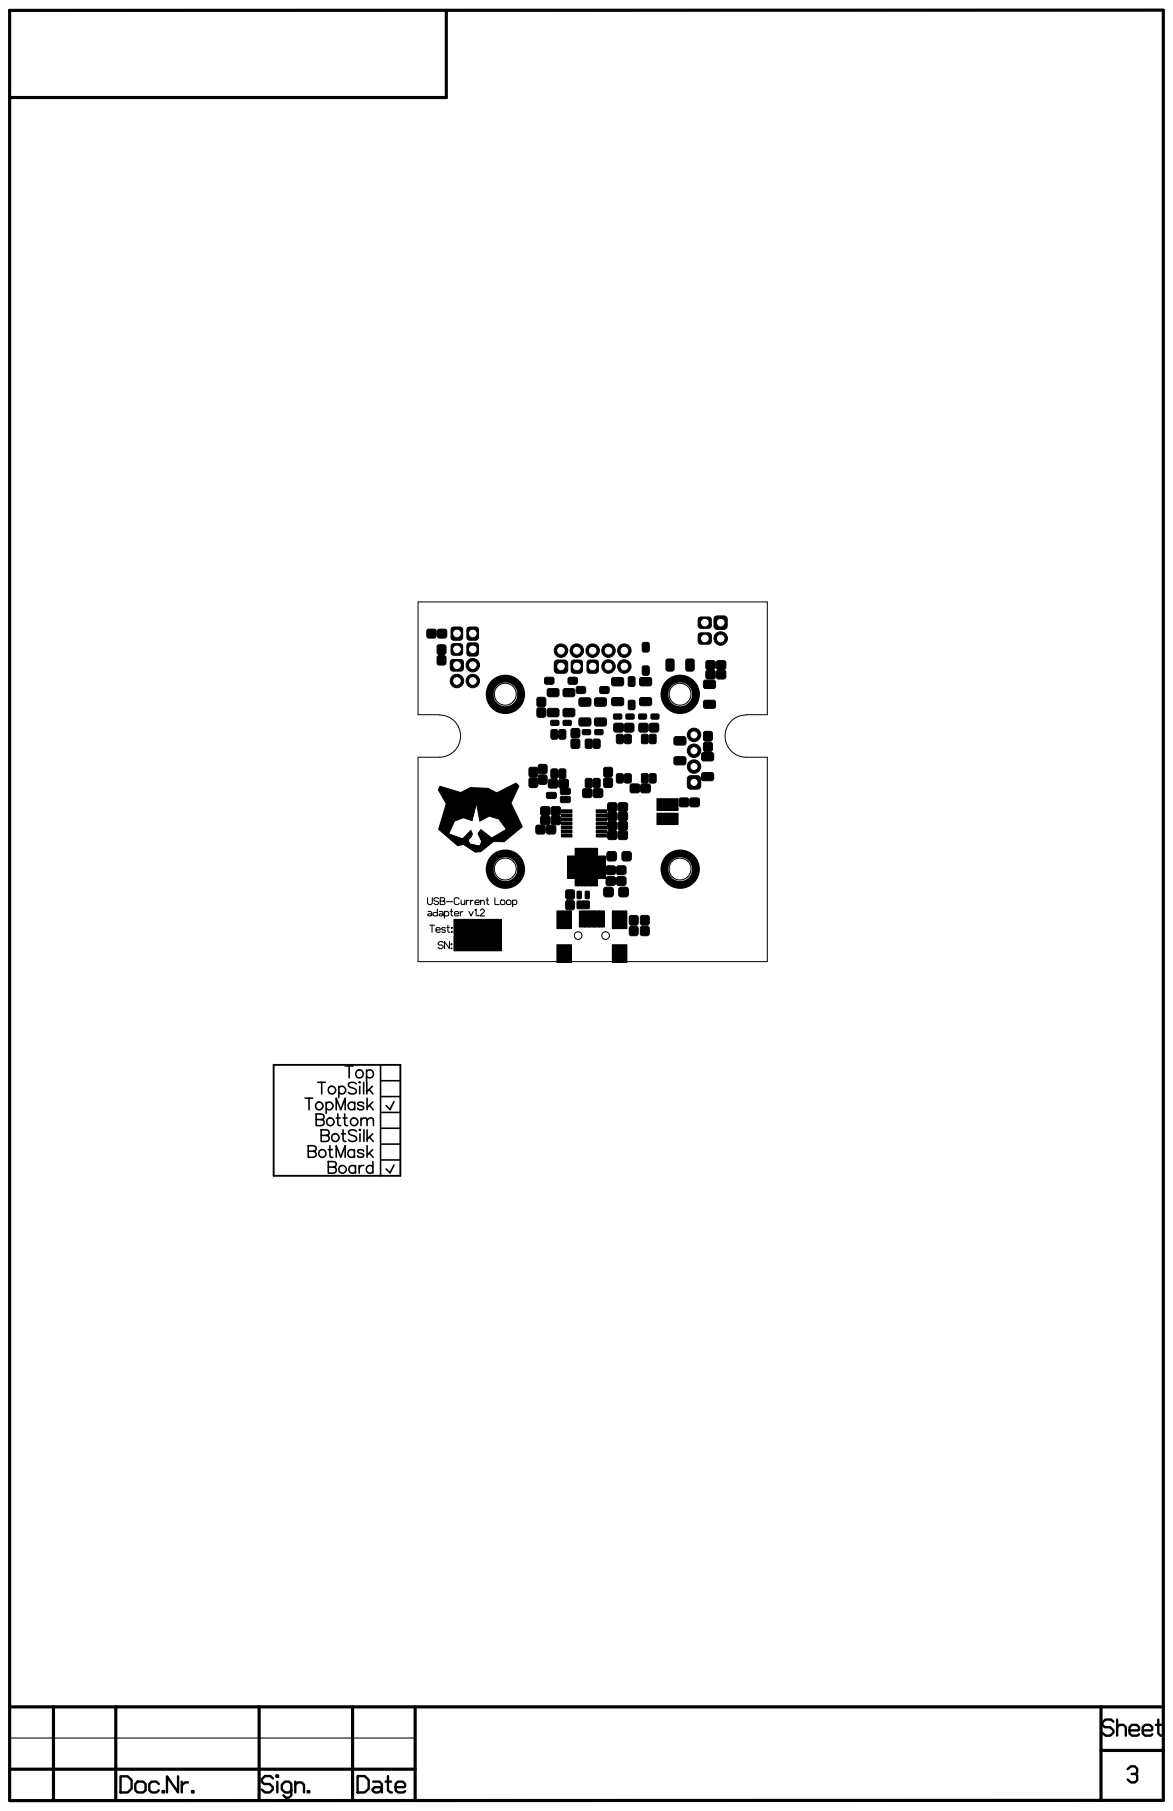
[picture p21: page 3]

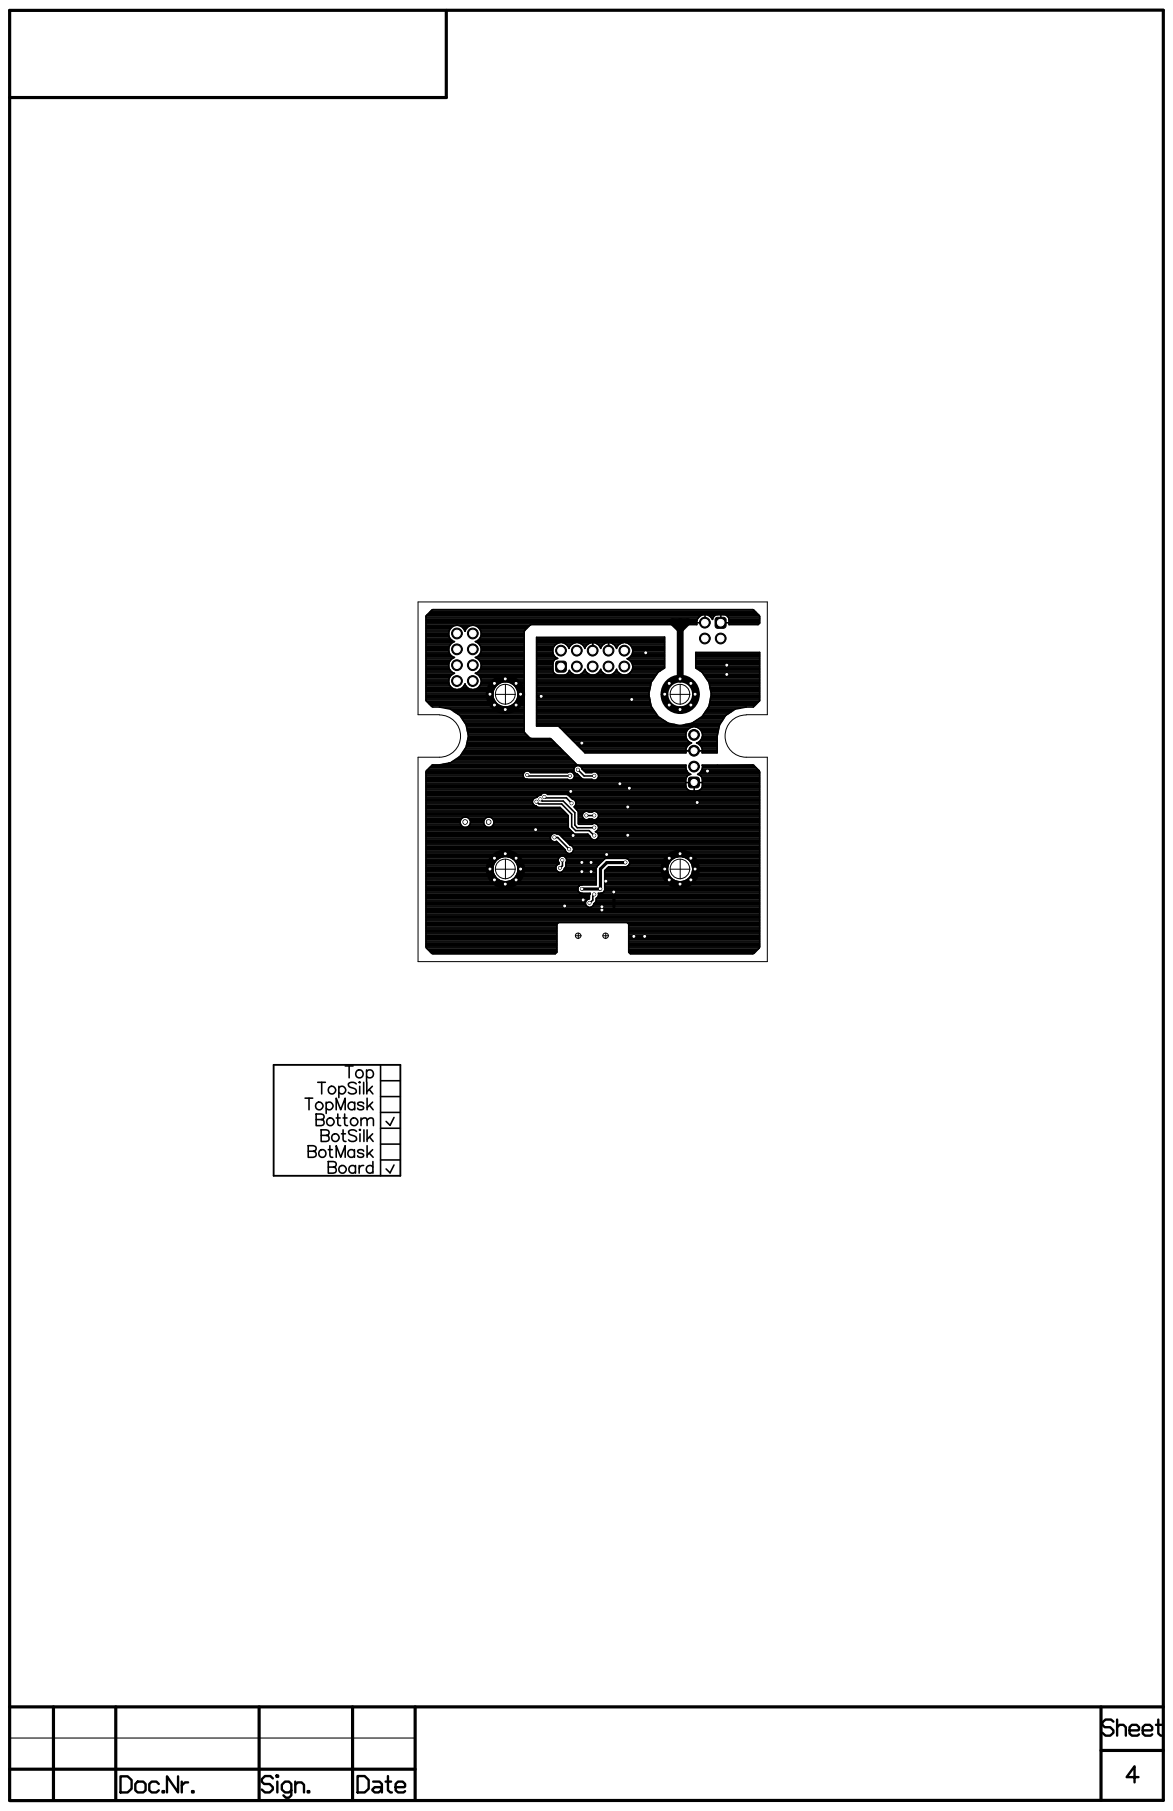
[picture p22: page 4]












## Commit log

2019-07-17 pcb added
2019-10-06 sch added, more files to come
    [usb_cl_interface_v_1_0_(pcad2006).sch]
2019-10-06 some CAD files added
    [plastic_panels.dxf, stickers.dxf]
2019-10-06 pcb added to documentation
    [usb_cl_interface_v_1_0_(pcad2006).sch]
2019-10-08 documentation fixed for v1.0, datasheets added
    [usb_cl_interface_v_1_0_(pcad2006).sch]
2019-10-08 assembly drawing added
2019-10-20 v1.0 BOM added
    [stickers.dxf]
2019-10-23 8-pin adapter almost finished
2019-10-24 8-pin adapter finished, main board v1.2 work started
    [CL_INTERFACE_8PIN_ADAPTER_(PCAD2006).GBL, CL_INTERFACE_8PIN_ADAPTER_(PCAD2006).GBO, CL_INTERFACE_8PIN_ADAPTER_(PCAD2006).GBS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]
2019-11-04 8-pin adapter finished for ordered connectors
2019-11-30 PCB routing almost finished. DRC should be run and RefDes should be placed in order
2019-12-01 PCB routing finished
2019-12-02 sch according to pcb
    [usb_cl_interface_(pcad2006).sch, usb_cl_interface_v_1_0_(pcad2006).sch]
2019-12-02 two more small adapter boards made, schematics almost finished
    [CL_INTERFACE_8PIN_ADAPTER_(PCAD2006).GBL, CL_INTERFACE_8PIN_ADAPTER_(PCAD2006).GBO, CL_INTERFACE_8PIN_ADAPTER_(PCAD2006).GBS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]
2019-12-05 adapter boards in one design file, main board almost ready for fabrication, stencil ready, still have to find some pinouts
2019-12-13 small updates in PCB and SCH, PCB fully finished
    [usb_cl_interface_(pcad2006).sch]
2019-12-14 8 pin adapter finished. One more small pcb and project will be ready to be ordered
2019-12-14 I12 adapter board routec, but has to be checked
2019-12-27 8 pin adapter finished
2019-12-28 boards finished, sent to production
2020-01-22 schematics finished, added to documentation
    [usb_cl_interface_(pcad2006).sch]
2020-01-26 schematics finished and won't be changed. New dipswitch in BOM
    [usb_cl_interface_(pcad2006).sch]
2020-04-10 pcb folder cleaned up, accidentally damaged file restored
